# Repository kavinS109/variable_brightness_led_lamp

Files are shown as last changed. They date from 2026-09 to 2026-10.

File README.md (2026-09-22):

# Variable Brightness LED Lamp

A custom LED lamp designed from schematic through PCB, firmware,
mechanical enclosure, and final assembly.

## Requirements
	- The lamp shall provide a control mechanism that allows the user to turn the light on and off, and adjust its brightness. 
	- The lamp shall operate from a 5V DC input supplied from an AC-to-DC wall adapter. 
	- The lamp shall incorporate a custom PCB designed to fit within and mount to a 3D-printed enclosure.

## System Architecture
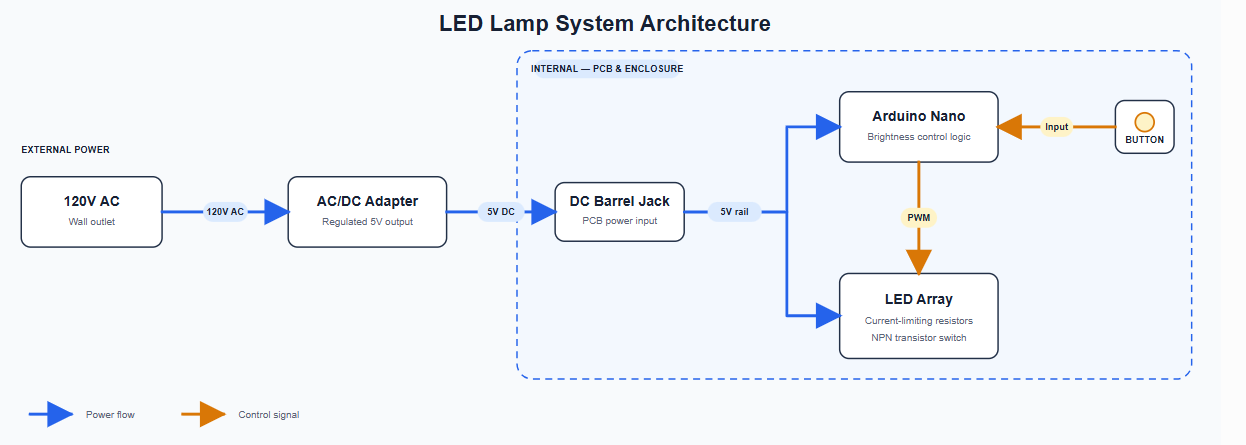
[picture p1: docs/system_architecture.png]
System Architecture


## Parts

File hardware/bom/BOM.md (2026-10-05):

# Bill of materials — ESP32 LED and encoder project

Prepared 5 October 2026. Currency: USD. Quantities are for one assembly.

Estimated component cost: **$17.85**, rounded planning budget **$18**. Allow roughly **$15–$25 for components**, excluding shipping, sales tax, tariffs, PCB/perfboard, wire, enclosure, encoder knob, power adapter and USB cable. Prices below are rounded budgeting allowances, not a supplier quote or a guaranteed purchasable cart. Pack minimums may increase checkout cost.

| Reference labels | Qty | Component / specification | Manufacturer / part | Est. unit | Est. extended |
|---|---:|---|---|---:|---:|
| R_LED1–R_LED5 | 5 | 91 Ω, ±5%, ¼ W, axial carbon-film resistor | Yageo CFR-25JR-52-91R | $0.10 | $0.50 |
| R_Base | 1 | 240 Ω, ±5%, ¼ W, axial carbon-film resistor | Yageo CFR-25JR-52-240R | $0.10 | $0.10 |
| R_Base_PD | 1 | 47 kΩ, ±5%, ¼ W, axial carbon-film resistor; base pulldown | Yageo CFR-25JR-52-47K | $0.10 | $0.10 |
| R_ENC_A, R_ENC_B | 2 | 10 kΩ, ±5%, ¼ W, axial carbon-film resistor | Yageo CFR-25JR-52-10K | $0.10 | $0.20 |
| R_BTN | 1 | 10 kΩ, ±5%, ¼ W, axial carbon-film resistor | Yageo CFR-25JR-52-10K | $0.10 | $0.10 |
| D1–D5 | 5 | Blue LED, 5 mm through-hole, clear lens, 30° viewing angle | Inolux INL-5AB30 | $0.50 | $2.50 |
| C_ENC_A, C_ENC_B | 2 | 0.01 µF / 10 nF, ±5%, ceramic capacitor | Generic; voltage rating, dielectric and footprint to select | $0.30 | $0.60 |
| C_BTN | 1 | 0.1 µF / 100 nF, ±5%, ceramic capacitor | Generic; voltage rating, dielectric and footprint to select | $0.50 | $0.50 |
| Q1 | 1 | 2N3904 NPN transistor, TO-92, 40 V, 200 mA maximum | Diotec 2N3904; packaging suffix to select | $0.25 | $0.25 |
| U1 | 1 | ESP32 DEVKIT V1 development board | DOIT / compatible; exact supplier and pin count to select | $8.00 | $8.00 |
| J1 | 1 | 5.5 × 2.1 mm DC barrel jack, right-angle, through-hole PCB mount | Tensility 54-00166 | $1.00 | $1.00 |
| ENC1 | 1 | Rotary encoder with momentary pushbutton | Bourns PEC11H series; full ordering code to select | $4.00 | $4.00 |
| **Total** | **22** | **10 resistors, 5 LEDs, 3 capacitors, 1 transistor, 1 board, 1 jack, 1 encoder** | | | **$17.85** |

## Consolidated resistor purchase quantities

| Resistance | Quantity | Specification |
|---|---:|---|
| 91 Ω | 5 | Yageo, ±5%, ¼ W |
| 240 Ω | 1 | Yageo, ±5%, ¼ W |
| 47 kΩ | 1 | Yageo, ±5%, ¼ W |
| 10 kΩ | 3 | Yageo, ±5%, ¼ W |

## Datasheet sources

- INL-5AX30 series_DS(1).pdf: blue INL-5AB30 variant, electrical characteristics and ordering table.
- 54-00166_DS(1).pdf: Tensility right-angle 5.5 × 2.1 mm barrel jack.
- PEC11H_DS(1).pdf: Bourns encoder ordering options and suggested filter circuit.
- 2n3904_DS(2).pdf: Diotec 2N3904 ratings and TO-92 package.

## Price references checked 5 October 2026

Price pages can change. Budget allowances intentionally use rounded values and mix supplier references; they are not a single-vendor quote.

- Yageo 91 Ω resistor: DigiKey lists $0.10 at quantity 1. Other resistor values use the same $0.10 allowance rather than separately verified quotes: https://www.digikey.com/en/products/filter/through-hole-resistors/91-ohms/53
- Inolux INL-5AB30: product identified at DigiKey; a secondary listing showed $0.51. $0.50 is a budgeting allowance, not verified DigiKey pricing: https://www.digikey.com/en/products/detail/inolux/INL-5AB30/7604625 and https://www.lanka-micro.com/manufacturers/Inolux?page=18
- Tensility 54-00166: manufacturer page showed $0.53; quantity conditions were not established, so $1.00 is allowed: https://www.tensility.com/products/54-00166
- PEC11H encoder: Mouser PEC11H family listing showed $3.37 for PEC11H-4020F-S0016 at quantity 1: https://www.mouser.com/en/c/passive-components/encoders/?m=Bourns&with+switch=Pushbutton+Switch
- ESP32 DEVKIT V1: marketplace listing showed $7.19 for a 30-pin development board; $8.00 allowed, supplier/model to confirm: https://www.walmart.com/ip/17700363178
- Diotec 2N3904: DigiKey related-product listing showed $0.14; $0.25 allowed: https://www.digikey.com/en/products/detail/onsemi/2N3904/25602699

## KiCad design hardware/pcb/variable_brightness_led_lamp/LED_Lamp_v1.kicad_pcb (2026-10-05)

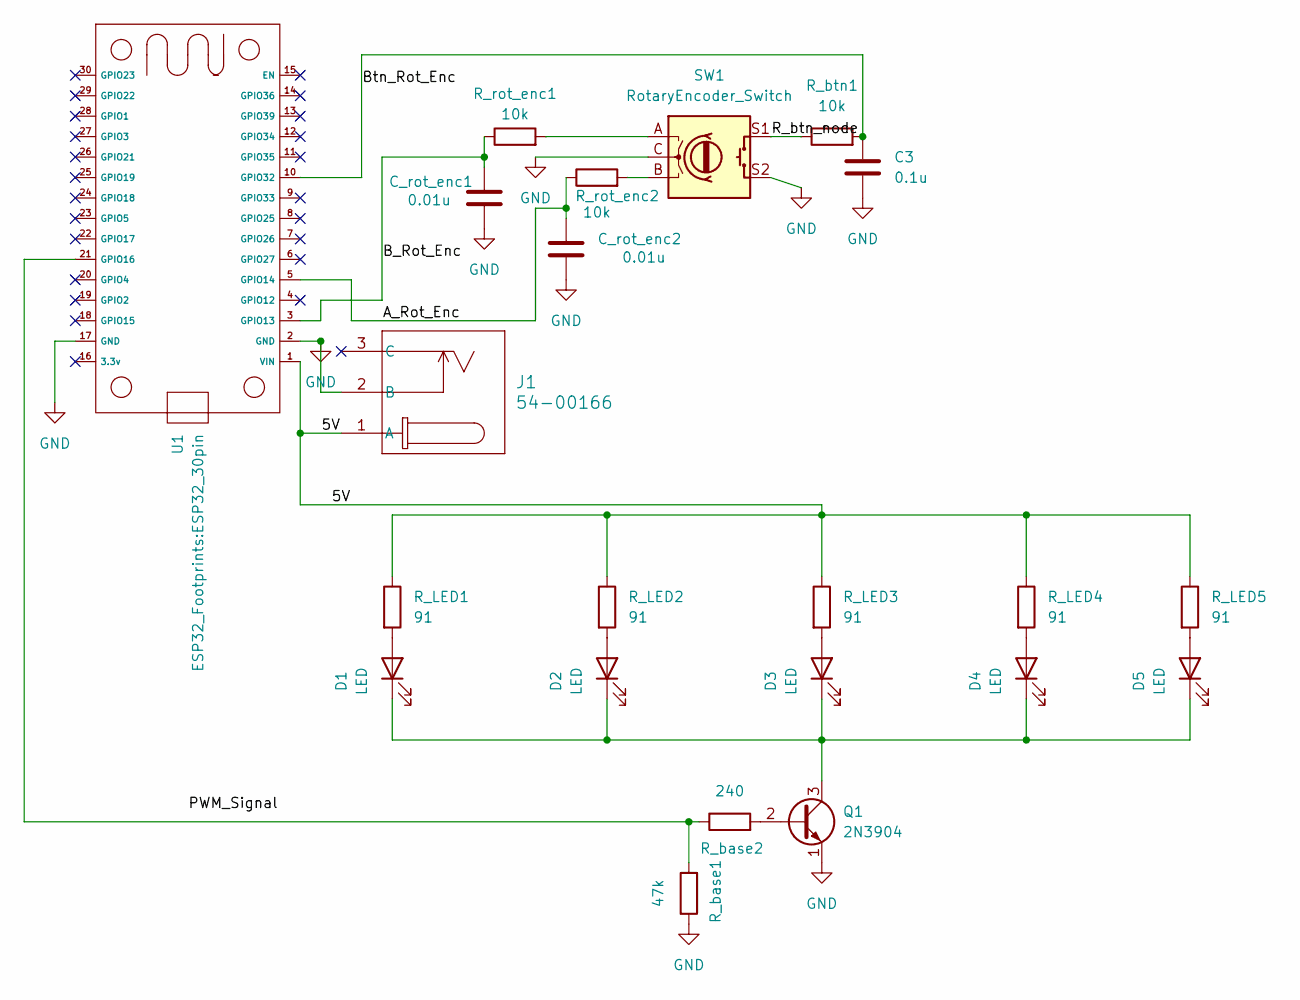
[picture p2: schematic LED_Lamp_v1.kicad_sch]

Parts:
C3: 0.1u; C_Disc_D5.0mm_W2.5mm_P2.50mm
C_rot_enc1, C_rot_enc2: 0.01u; C_Disc_D5.0mm_W2.5mm_P2.50mm
D1, D2, D3, D4, D5: LED; LED_D5.0mm
J1: 54-00166; CONN3_54-00166_TEN
Q1: 2N3904; TO-92_Inline
R_LED1, R_LED2, R_LED3, R_LED4, R_LED5: 91; R_Axial_DIN0207_L6.3mm_D2.5mm_P7.62mm_Horizontal
R_base1: 47k; R_Axial_DIN0207_L6.3mm_D2.5mm_P7.62mm_Horizontal
R_base2: 240; R_Axial_DIN0207_L6.3mm_D2.5mm_P7.62mm_Horizontal
R_btn1: 10k; R_Axial_DIN0207_L6.3mm_D2.5mm_P7.62mm_Horizontal
R_rot_enc1, R_rot_enc2: 10k; R_Axial_DIN0207_L6.3mm_D2.5mm_P7.62mm_Horizontal
SW1: RotaryEncoder_Switch; RotaryEncoder_Alps_EC11E-Switch_Vertical_H20mm_CircularMoun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
U1: ESP32_30pin

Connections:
/5V: J1.1 (A), R_LED1.1, R_LED2.1, R_LED3.1, R_LED4.1, R_LED5.1, U1.1 (VIN)
/A_Rot_Enc: C_rot_enc2.1, R_rot_enc2.1, U1.5 (GPIO14)
/B_Rot_Enc: C_rot_enc1.1, R_rot_enc1.1, U1.3 (GPIO13)
/Btn_Rot_Enc: C3.1, R_btn1.2, U1.10 (GPIO32)
/R_btn_node: R_btn1.1, SW1.S1
GND: C3.2, C_rot_enc1.2, C_rot_enc2.2, J1.2 (B), Q1.1 (E), R_base1.1, SW1.C, SW1.S2, U1.2 (GND), U1.17 (GND)
unnamed: D1.2 (A), R_LED1.2
unnamed: D1.1 (K), D2.1 (K), D3.1 (K), D4.1 (K), D5.1 (K), Q1.3 (C)
unnamed: D2.2 (A), R_LED2.2
unnamed: D3.2 (A), R_LED3.2
unnamed: D4.2 (A), R_LED4.2
unnamed: D5.2 (A), R_LED5.2
unnamed: Q1.2 (B), R_base2.2
unnamed: R_rot_enc1.2, SW1.A
unnamed: R_rot_enc2.2, SW1.B
unnamed: R_base1.2, R_base2.1, U1.21 (GPIO16)

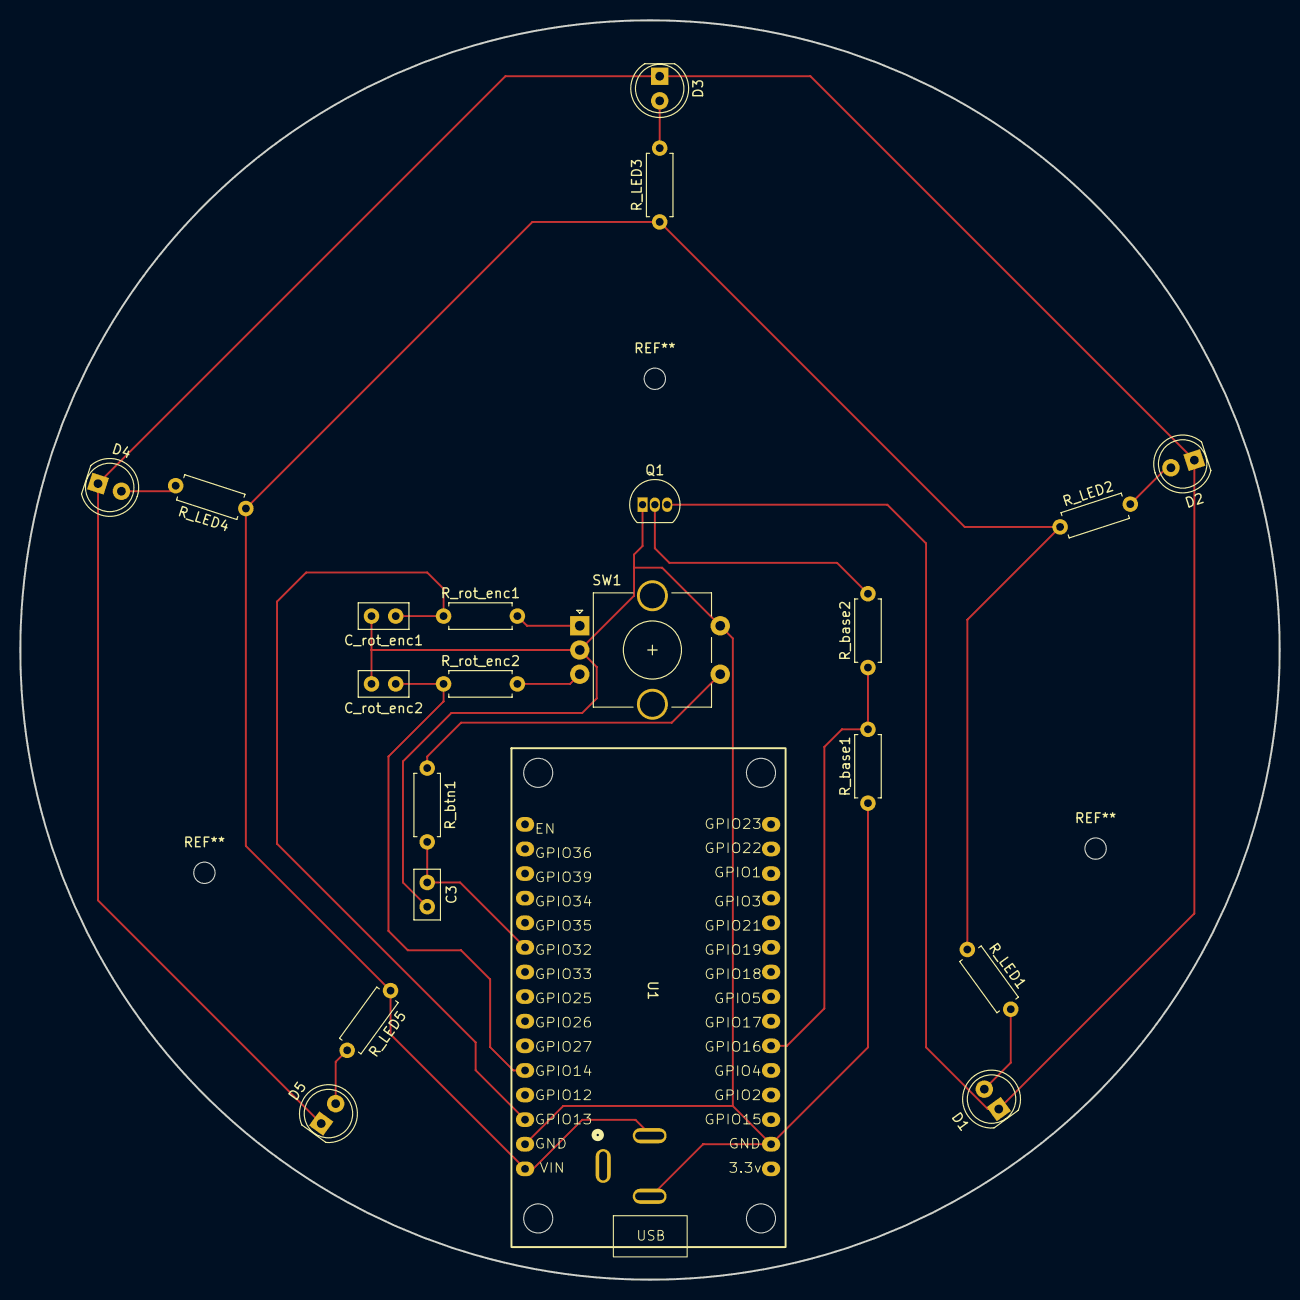
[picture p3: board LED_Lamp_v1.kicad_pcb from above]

Board: 2 copper layers, 130.0 x 130.0 mm, 22 parts (1 on the bottom side), 16 nets.

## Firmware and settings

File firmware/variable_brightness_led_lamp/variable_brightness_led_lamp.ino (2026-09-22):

const int bjtPin = 3;      // PWM output to BJT base
const int buttonPin = 2;   // Pushbutton input

// PWM values corresponding to 0%, 25%, 75%, and 100%
const int brightnessLevels[] = {0, 64, 191, 255};
const int numLevels = 4;

int currentLevel = 0;

// Button state tracking
int lastButtonState = HIGH;
int buttonState = HIGH;

// Debouncing
unsigned long lastDebounceTime = 0;
const unsigned long debounceDelay = 50;

void setup() {
  pinMode(bjtPin, OUTPUT);
  pinMode(buttonPin, INPUT_PULLUP);

  // Start with LED off
  analogWrite(bjtPin, brightnessLevels[currentLevel]);
}

void loop() {
  int reading = digitalRead(buttonPin);

  // Button input changed - restart debounce timer
  if (reading != lastButtonState) {
    lastDebounceTime = millis();
  }

  // Only accept the change if it remains stable
  if ((millis() - lastDebounceTime) > debounceDelay) {

    if (reading != buttonState) {
      buttonState = reading;

      // Button has just been pressed
      if (buttonState == LOW) {
        currentLevel++;

        // Return to 0% after 100%
        if (currentLevel >= numLevels) {
          currentLevel = 0;
        }

        analogWrite(bjtPin, brightnessLevels[currentLevel]);
      }
    }
  }

  lastButtonState = reading;
}

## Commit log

2026-10-05 Add Initial PCB design
    [LED_Lamp_v1.kicad_pcb, LED_Lamp_v1.kicad_sch, LED_lamp_spice_test.kicad_sch]
2026-10-05 Add Initial BOM
2026-10-30 firmware-update, PCB-final
